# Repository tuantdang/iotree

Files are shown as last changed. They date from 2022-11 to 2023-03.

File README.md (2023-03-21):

## IoTree: A Battery-free Wearable System with Biocompatible Sensors for Continuous Tree Health Monitoring

[Project Page](https://github.com/tuantdang/iotree) | [Paper](https://dl.acm.org/doi/pdf/10.1145/3495243.3567652) | [Video](https://www.youtube.com/watch?v=8DUfOcuPwIk&ab_channel=TuanDang)

## Author Information
- [Tuan Dang,  University of Texas at Arlington](https://www.tuandang.info/)
- [Trung Tran,  Sungkyunkwan University](https://scholar.google.com/citations?user=2bYMOpEAAAAJ&hl=en)
- [Khang Nguyen,  University of Texas at Arlington](https://mkhangg.com/)
- [Tien Pham,  University of Texas at Arlington](https://sakewebsite.z19.web.core.windows.net/)
- [Nhat Pham, University of Oxford](https://www.nhatpham.info/)
- [Tam Vu, University of Colorado Boulder](http://mnslab.org/tamvu/)
- [Phuc Nguyen,  University of Texas at Arlington](http://wsslab.org/vpnguyen/)

 <p align="center">
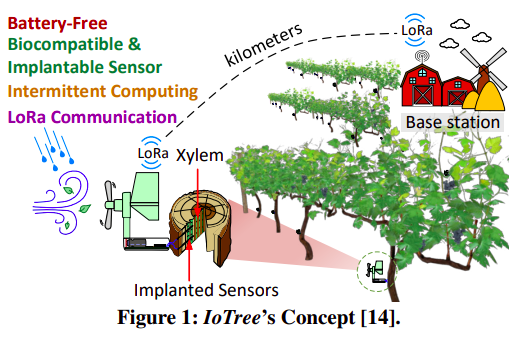
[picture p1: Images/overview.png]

</p>

## Abstract
In this paper, we present a low-maintenance, wind-powered, batteryfree, biocompatible, tree wearable, and intelligent sensing system,
namely IoTree, to monitor water and nutrient levels inside a living tree. IoTree system includes tiny-size, biocompatible, and implantable sensors that continuously measure the impedance variations inside the living tree’s xylem, where water and nutrients are
transported from the root to the upper parts. The collected data are
then compressed and transmitted to a base station located at up to 1.8
kilometers (approximately 1.1 miles) away. The entire IoTree system
is powered by wind energy and controlled by an adaptive computing
technique called block-based intermittent computing, ensuring the
forward progress and data consistency under intermittent power and
allowing the firmware to execute with the most optimal memory and
energy usage. We prototype IoTree that opportunistically performs
sensing, data compression, and long-range communication tasks
without batteries. During in-lab experiments, IoTree also obtains the
accuracy of 91.08% and 90.51% in measuring 10 levels of nutrients,
𝑁𝐻3 and 𝐾2𝑂, respectively. While tested with Burkwood Viburnum
and White Bird trees in the indoor environment, IoTree data strongly
correlated with multiple watering and fertilizing events. We also
deployed IoTree on a grapevine farm for 30 days, and the system is
able to provide sufficient measurements every day
 
 ## System Architecture
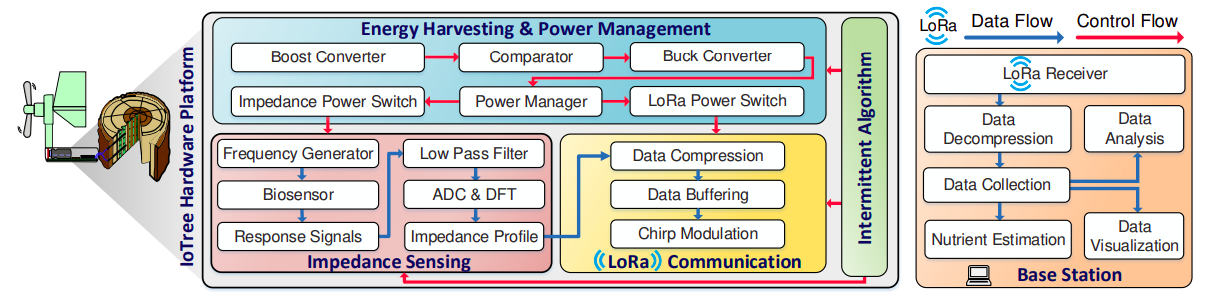
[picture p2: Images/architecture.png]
 
 
 ## Prototype
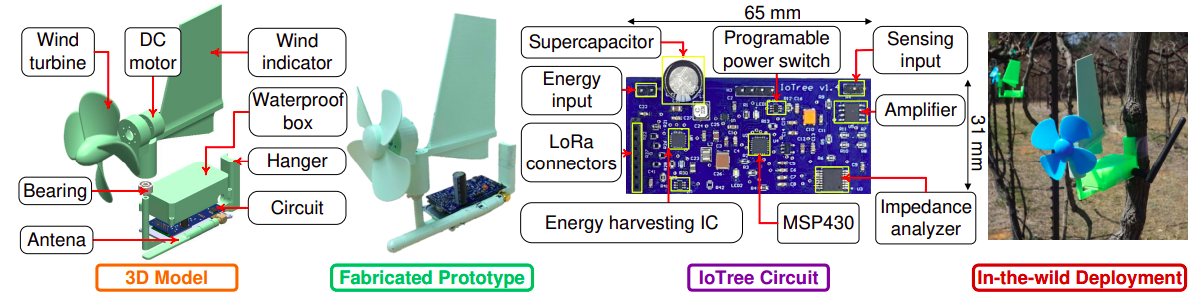
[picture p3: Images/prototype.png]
 
 
 ## Results
<p align="center">
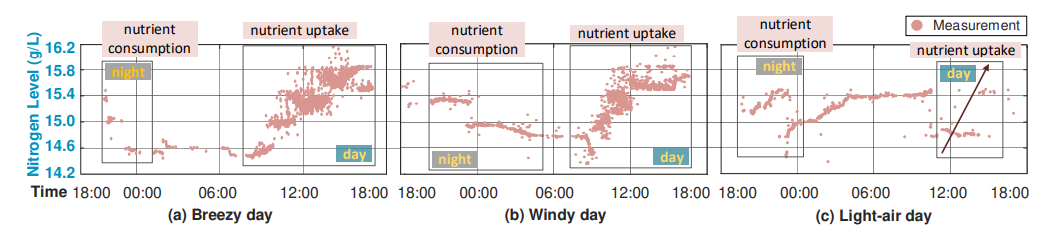
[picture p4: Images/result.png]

</p>

## Requirement
- Code Composer Studio 10.0
- MatLab
- Python 3.7 or above

## Acknowledgments

## Citing
```
@inproceedings{dang2022iotree,
  title={ioTree: a battery-free wearable system with biocompatible sensors for continuous tree health monitoring},
  author={Dang, Tuan and Tran, Trung and Nguyen, Khang and Pham, Tien and Pham, Nhat and Vu, Tam and Nguyen, Phuc},
  booktitle={Proceedings of the 28th Annual International Conference on Mobile Computing And Networking},
  pages={352--366},
  year={2022}
}
```

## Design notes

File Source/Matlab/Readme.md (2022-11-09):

 # GUI tool to collect data with indoor experiments
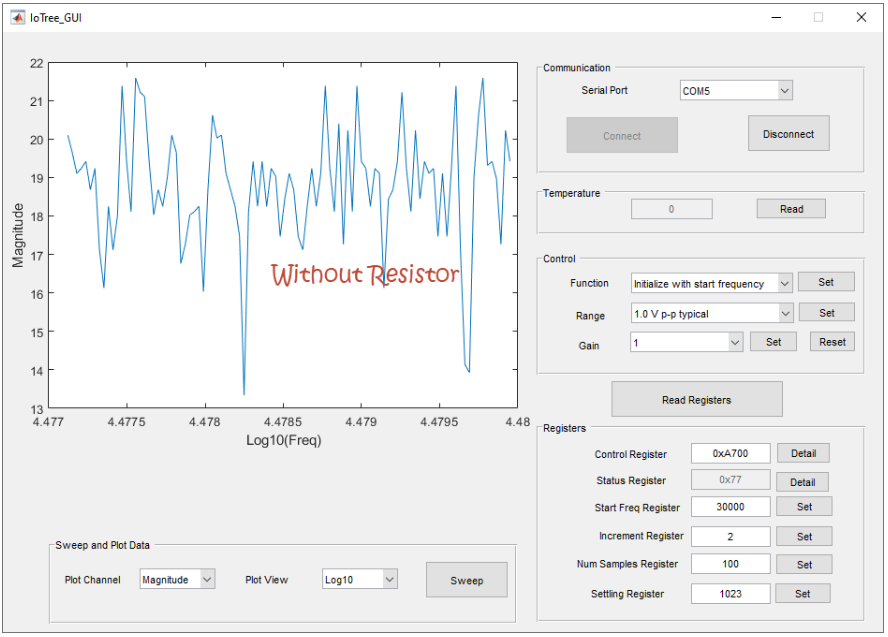
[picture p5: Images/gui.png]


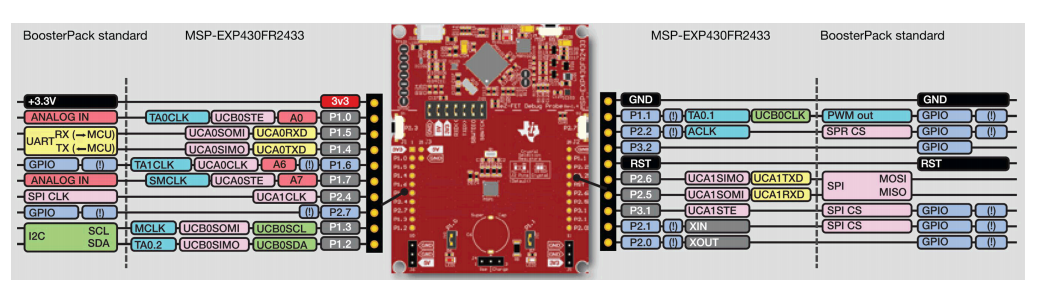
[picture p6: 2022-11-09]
Source/IoTree_MSP430FR2433_TestWisp/header-pinout.png

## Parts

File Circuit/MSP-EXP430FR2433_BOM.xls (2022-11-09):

Item # | Designator | Quantity | Manufacturer | PartNumber | Description | Supplier Part Number 1 | Note | REACH Compliant | RoHS Compliant
1 | !PCB | 1 | CM |  | MSP-EXP430FR2433 PCB
2 | !USB | 1 | Assman WSW | AK67421-0.3 | Cable, USB-A to micro USB-B, 0.3 m |  |  | Y | Y
3 | C1, C112 | 2 | MuRata | GRM155R71H102KA01D | CAP, CERM, 1000 pF, 50 V, +/- 10%, X7R, 0402 | 490-1303-1-ND |  | Y | Y
4 | C2, C3 | 2 | MuRata | GRM1555C1E120JA01D | CAP, CERM, 12 pF, 25 V, +/- 5%, C0G/NP0, 0402 | 81-GRM1555C1E120JA1D |  | Y | Y
5 | C4 | 1 | MuRata | GRM155R61H104ME14D | CAP, CERM, 0.1 µF, 50 V, +/- 20%, X5R, 0402 | GRM155R61H104ME14D-ND |  | Y | Y
6 | C5 | 1 | MuRata | GRM188R60J106ME84 | CAP, CERM, 10 µF, 6.3 V, +/- 20%, X5R, 0603 | 490-7316-1-ND |  | Y | Y
7 | C101 | 1 | MuRata | GRM155R61C474KE01 | CAP, CERM, 0.47 µF, 16 V, +/- 10%, X5R, 0402 |  |  | Y | Y
8 | C102, C107 | 2 | MuRata | GRM188R61C224KA88D | CAP, CERM, 0.22 µF, 16 V, +/- 10%, X5R, 0603 | GRM188R61C224KA88D-ND |  | Y | Y
9 | C103, C105, C113, C114, C118, C120, C121, C124, C125 | 9 | MuRata | GRM155R61A104KA01D | CAP, CERM, 0.1 µF, 10 V, +/- 10%, X5R, 0402 | 490-1318-1-ND |  | Y | Y
10 | C104 | 1 | Vishay-Sprague | 293D106X0010A2TE3 | CAP, TA, 10 µF, 10 V, +/- 20%, 3.4 ohm, SMD | 718-1118-1-ND |  | Y | Y
11 | C106, C109 | 2 | Vishay-Sprague | 293D475X9010A2TE3 | CAP, TA, 4.7 µF, 10 V, +/- 10%, 5 ohm, SMD | 718-1146-1-ND |  | Y | Y
12 | C108 | 1 | MuRata | GRM185R61A105KE36D | CAP, CERM, 1 µF, 10 V, +/- 10%, X5R, 0603 | 490-3893-1-ND |  | Y | Y
13 | C110, C111 | 2 | MuRata | GRM1555C1H100JA01D | CAP, CERM, 10 pF, 50 V, +/- 5%, C0G/NP0, 0402 | 81-GRM1555C1H100JA1D |  | Y | Y
14 | C115, C116, C122, C123 | 4 | MuRata | GRM1555C1H330JA01D | CAP, CERM, 33 pF, 50 V, +/- 5%, C0G/NP0, 0402 | 81-GRM1555C1H330JA1D |  | Y | Y
15 | C117, C119 | 2 | MuRata | GRM188R61C475KAAJ | CAP, CERM, 4.7 µF, 16 V, +/- 10%, X5R, 0603 | 490-10481-1-ND | Use Exact Part | Y | Y
16 | C126 | 1 | MuRata | GRM155R61A224KE19D | CAP, CERM, 0.22 µF, 10 V, +/- 10%, X5R, 0402 | 490-3910-1-ND |  | Y | Y
17 | D101, D102 | 2 | NXP Semiconductor | BAS40-05W,115 | Diode, Schottky, 40 V, 0.12 A, AEC-Q101, SOT-323 | 568-7982-1-ND | Use Exact Part | Y | Y
18 | IC101 | 1 | Texas Instruments | TLV70033DSET | Single Output LDO, 200 mA, Fixed 3.3 V Output, 2 to 5.5 V Input, with Low IQ, 6-pin WSON (DSE), -40 to 125 degC, Green (RoHS & no Sb/Br) | 296-25215-2-ND | TI Provided | Y | Y
19 | IC102 | 1 | Texas Instruments | TPD4E004DRYR | ESD-Protection Array for High-Speed Data Interfaces, 4 Channels, -40 to +85 degC, 6-pin SON (DRY), Green (RoHS & no Sb/Br) | 296-23618-2-ND | TI Provided | Y | Y
20 | IC103 | 1 | Texas Instruments | TS5A21366RSER | 0.75-Ohm DUAL SPST ANALOG SWITCH WITH 1.8-V COMPATIBLE INPUT LOGIC, RSE0008A (UQFN-8) |  | TI Provided | Y | Y
21 | J1, J2 | 2 | Samtec | SSQ-110-03-F-S | Receptacle, 2.54mm, 10x1, Gold, TH | 2283783 | Booster Pack 20 pin J1, Booster Pack 20 pin J2 | Y | Y
22 | J3 | 1 | Samtec | SSQ-102-03-F-S | Receptacle, 2.54mm, 2x1, Gold, TH | 2283777 | Booster Pack 20 pin J3 | Y | Y
23 | J4, J5, J6 | 3 | Sullins Connector Solutions | PEC03SAAN | Header, 100mil, 3x1, Tin, TH | S1012E-03-ND |  | Y | Y
24 | J10, J11 | 2 | Samtec | TSW-102-07-G-S | Header, 100mil, 2x1, Gold, TH | SAM1029-02-ND |  | Y | Y
25 | J101 | 1 | Sullins Connector Solutions | PEC07DAAN | Header, 100mil, 7x2, Tin, TH | S2012E-07-ND |  | Y | Y
26 | J102 | 1 | Molex | 1051640001 | Receptacle, USB 2.0, Micro B, 5 Position, R/A, SMT | WM11263CT-ND | Use Exact Part | Y | Y
27 | L101 | 1 | Taiyo Yuden | CBC2518T2R2M | Inductor, Wirewound, Ceramic, 2.2 µH, 0.89 A, 0.13 ohm, SMD | 587-1618-1-ND | Use Exact Part | Y | Y
28 | L102, L103 | 2 | Wurth Elektronik | 742792622 | Ferrite Bead, 180 ohm @ 100 MHz, 0.5 A, 0603 | 732-1580-1-ND |  | Y | Y
29 | LED1, LED101 | 2 | Lite-On | LTST-C190CKT | LED, Red, SMD | 160-1181-1-ND |  | Y | Y
30 | LED2, LED102 | 2 | Lite-On | LTST-C190GKT | LED, Green, SMD | 160-1183-1-ND |  | Y | Y
31 | MSP1 | 1 | Texas Instruments | MSP430FR2433IRGER | MSP430FR2433 16 MHz Ultra-Low-Power Microcontroller with 16 KB FRAM, 4 KB RAM, 19 IO, 4 Timers, RGE0024H (VQFN-24) |  | TI Provided | Y | Y
32 | MSP101 | 1 | Texas Instruments | MSP430F5528IRGCT | 25 MHz Mixed Signal Microcontroller with 128 KB Flash, 8192 B SRAM and 47 GPIOs, -40 to 85 degC, 64-pin QFN (RGC), Green (RoHS & no Sb/Br) |  | TI Provided | Y | Y
33 | MSP102 | 1 | Texas Instruments | MSP430G2452IRSA16R | 16 MHz Mixed Signal Microcontroller with 8 KB Flash, 256 B SRAM and 16 GPIOs, 16-pin QFN (RSA), Green (RoHS & no Sb/Br) |  | TI Provided | Y | Y
34 | Q1 | 1 | Epson | X1A0001410014 | Crystal, 32.768 KHz, 12.5 pF, SMD |  | Use Exact Part, TI Provided | Y | Y
35 | Q101 | 1 | MuRata | CSTCR4M00G15L99-R0 | Resonator, 4MHz, 39pF SMD | 490-7861-1-ND | Use Exact Part | Y | Y
36 | R1 | 1 | Yageo America | RC0402FR-0747KL | RES, 47.0 k, 1%, 0.0625 W, 0402 | 311-47.0KLRCT-ND |  | Y | Y
37 | R4, R5 | 2 | Vishay-Dale | CRCW06030000Z0EA | RES, 0, 5%, 0.1 W, 0603 | 541-0.0GCT-ND |  | Y | Y
38 | R6 | 1 | Yageo America | RC0402FR-07470RL | RES, 470, 1%, 0.063 W, 0402 | 311-470LRCT-ND |  | Y | Y
39 | R7 | 1 | Vishay-Dale | CRCW0402392RFKED | RES, 392, 1%, 0.063 W, 0402 | 541-392LCT-ND |  | Y | Y
40 | R8 | 1 | Vishay-Dale | CRCW120622R0JNEA | RES, 22, 5%, 0.25 W, 1206 | 541-22ECT-ND |  | Y | Y
41 | R101, R120 | 2 | Vishay-Dale | CRCW0402470RJNED | RES, 470, 5%, 0.063 W, 0402 | 541-470JCT-ND |  | Y | Y
42 | R102 | 1 | Vishay-Dale | CRCW0402390RJNED | RES, 390, 5%, 0.063 W, 0402 | 541-390JCT-ND |  | Y | Y
43 | R103, R104 | 2 | Vishay-Dale | CRCW040227R0JNED | RES, 27, 5%, 0.063 W, 0402 | 541-27JCT-ND |  | Y | Y
44 | R105 | 1 | Vishay-Dale | CRCW04021K40FKED | RES, 1.40 k, 1%, 0.063 W, 0402 | 541-1.40KLCT-ND |  | Y | Y
45 | R106 | 1 | Vishay-Dale | CRCW04021M00JNED | RES, 1.0 M, 5%, 0.063 W, 0402 | 541-1.0MJCT-ND |  | Y | Y
46 | R107, R108 | 2 | TE Connectivity | CRG0402F4K7 | RES, 4.70 k, 1%, 0.063 W, 0402 | A121542CT-ND |  | Y | Y
47 | R109 | 1 | Vishay-Dale | CRCW040247K0JNED | RES, 47 k, 5%, 0.063 W, 0402 | 541-47KJCT-ND |  | Y | Y
48 | R112, R113, R114, R115, R121, R122 | 6 | Vishay-Dale | CRCW0402221KFKED | RES, 221 k, 1%, 0.063 W, 0402 | 541-221KLCT-ND |  | Y | Y
49 | R116, R117 | 2 | Vishay-Dale | CRCW04024K70JNED | RES, 4.7 k, 5%, 0.063 W, 0402 | 541-4.7KJCT-ND |  | Y | Y
50 | R118 | 1 | Yageo America | RC0402FR-07820RL | RES, 820, 1%, 0.063 W, 0402 | 311-820LRCT-ND |  | Y | Y
51 | R119 | 1 | Vishay-Dale | CRCW04020000Z0ED | RES, 0, 5%, 0.063 W, 0402 | 541-0.0JCT-ND |  | Y | Y
52 | R123 | 1 | Vishay-Dale | CRCW040233K0JNED | RES, 33 k, 5%, 0.063 W, 0402 | 541-33KJCT-ND |  | Y | Y
53 | R124 | 1 | Vishay-Dale | CRCW0402240KFKED | RES, 240 k, 1%, 0.063 W, 0402 | 541-240KLCT-ND |  | Y | Y
54 | R125 | 1 | Vishay-Dale | CRCW0402150KFKED | RES, 150 k, 1%, 0.063 W, 0402 | 541-150KLCT-ND |  | Y | Y
55 | R126 | 1 | Vishay-Dale | CRCW04022K20FKED | RES, 2.20 k, 1%, 0.063 W, 0402 | 541-2.20KLCT-ND |  | Y | Y
56 | R127 | 1 | Panasonic | ERJ-2RKF3301X | RES, 3.30 k, 1%, 0.1 W, AEC-Q200 Grade 0, 0402 | P3.30KLCT-ND |  | Y | Y
57 | R128 | 1 | Vishay-Dale | CRCW04026K81FKED | RES, 6.81 k, 1%, 0.063 W, 0402 | 541-6.81KLCT-ND |  | Y | Y
58 | R129, R130 | 2 | Vishay-Dale | CRCW040210R0FKED | RES, 10.0, 1%, 0.063 W, 0402 | 541-10.0LCT-ND |  | Y | Y
59 | S1, S2, S3 | 3 | Diptronics | 1188E-1K2-V-TR | Switch, SPST, 0.05 A, 12 VDC, SMD |  |  | Y | Y
60 | SH-J10, SH-J11, SH-J101-1, SH-J101-2, SH-J101-3, SH-J101-4, SH-J101-5, SH-J101-6, SH-J101-7 | 9 | Samtec | SNT-100-BK-G | Shunt, 100mil, Gold plated, Black | SNT-100-BK-G-ND | J10: 1-2, J11: 1-2, J101: 1-2, J101: 3-4, J101: 5-6, J101: 7-8, J101: 9-10, J101: 11-12, J101: 13-14 | Y | Y
61 | T101 | 1 | Diodes Inc. | DMG1013UW-7 | MOSFET, P-CH, -20 V, -0.82 A, SOT-323 | DMG1013UW-7DICT-ND | Use Exact Part | Y | Y
62 | T102 | 1 | NXP Semiconductor | BC850CW,115 | Transistor, NPN, 45 V, 0.1 A, SOT-323 | 568-6076-1-ND | Use Exact Part | Y | Y
63 | C6 | 0 | Panasonic | EEC-S0HD224H | CAP, Electric Double Layer, 220000 µF, 5.5 V, +80/-20%, TH | P10788-ND | DNP
64 | C127 | 0 | MuRata | GRM1555C1H101JA01D | CAP, CERM, 100 pF, 50 V, +/- 5%, C0G/NP0, 0402 | 81-GRM1555C1H101JA1D | DNP
65 | R2, R3 | 0 | Vishay-Dale | CRCW06030000Z0EA | RES, 0, 5%, 0.1 W, 0603 | 541-0.0GCT-ND | DNP
66 | SH-J4 | 0 | Samtec | SNT-100-BK-G | Shunt, 100mil, Gold plated, Black | SNT-100-BK-G-ND | DNP, J4: 2
67 | TP101, TP102, TP103, TP104, TP105, TP106, TP107, TP108, TP109 | 0 | Keystone | 5001 | Test Point, Miniature, Black, TH | 36-5001-ND | DNP

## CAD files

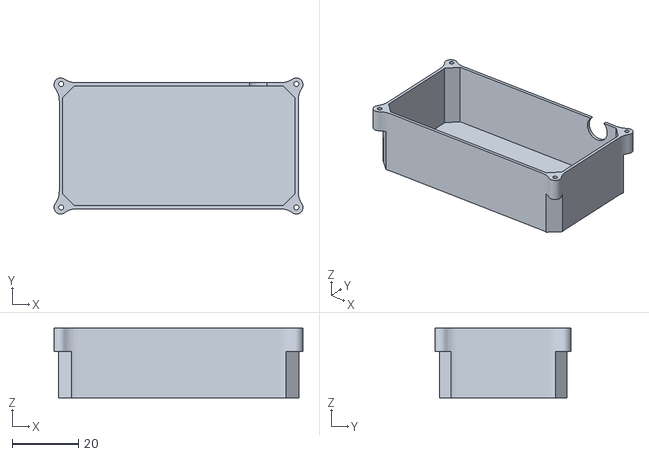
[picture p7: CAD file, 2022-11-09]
3D_Models/upper_box.STL
75.0 x 41.0 x 21.0

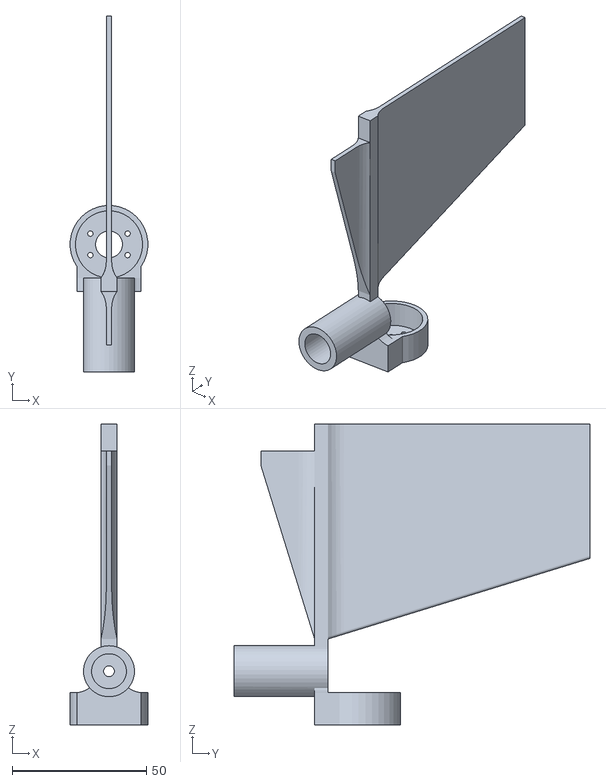
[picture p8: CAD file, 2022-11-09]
3D_Models/motor_mount_nav.STL
28.9 x 132.5 x 112.0

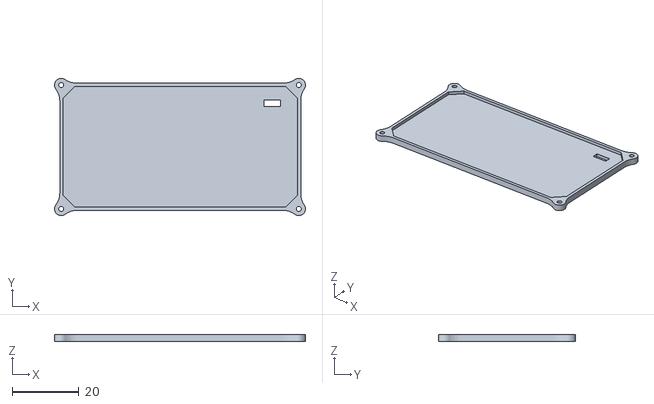
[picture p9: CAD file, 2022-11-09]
3D_Models/base.STL
75.0 x 41.0 x 2.00

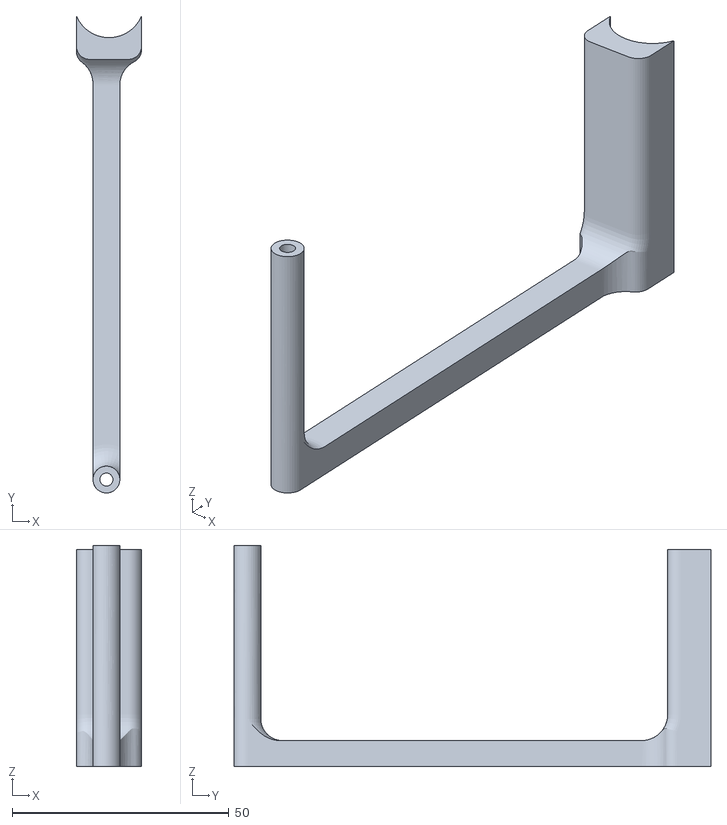
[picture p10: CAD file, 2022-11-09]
3D_Models/WindHarvester.STL
15.0 x 110.0 x 51.0

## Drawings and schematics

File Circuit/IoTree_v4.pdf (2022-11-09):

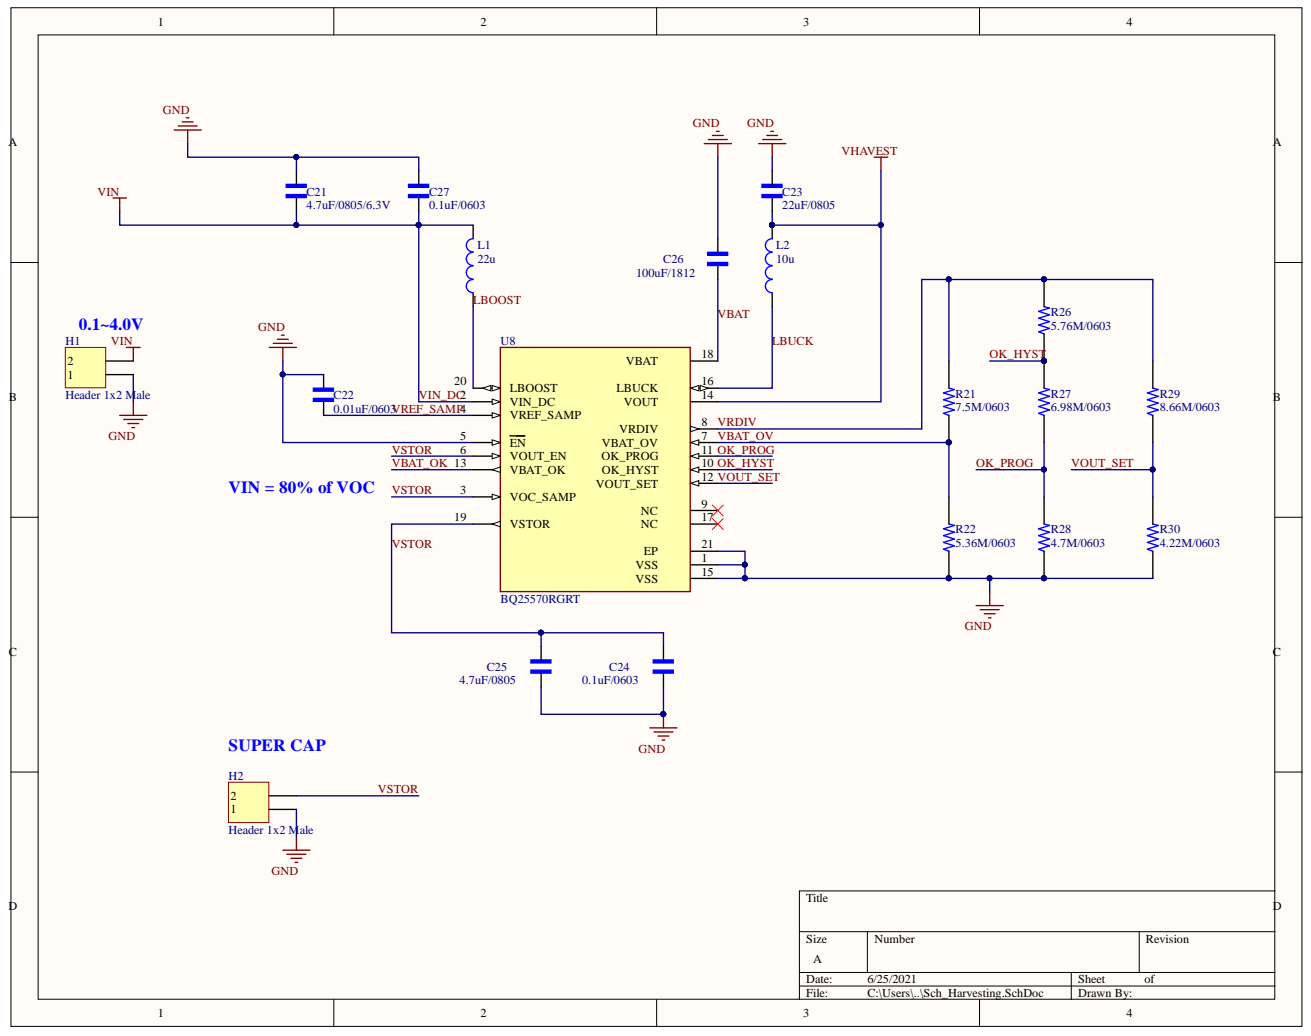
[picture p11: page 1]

VIN = 80% of VOC VSTOR

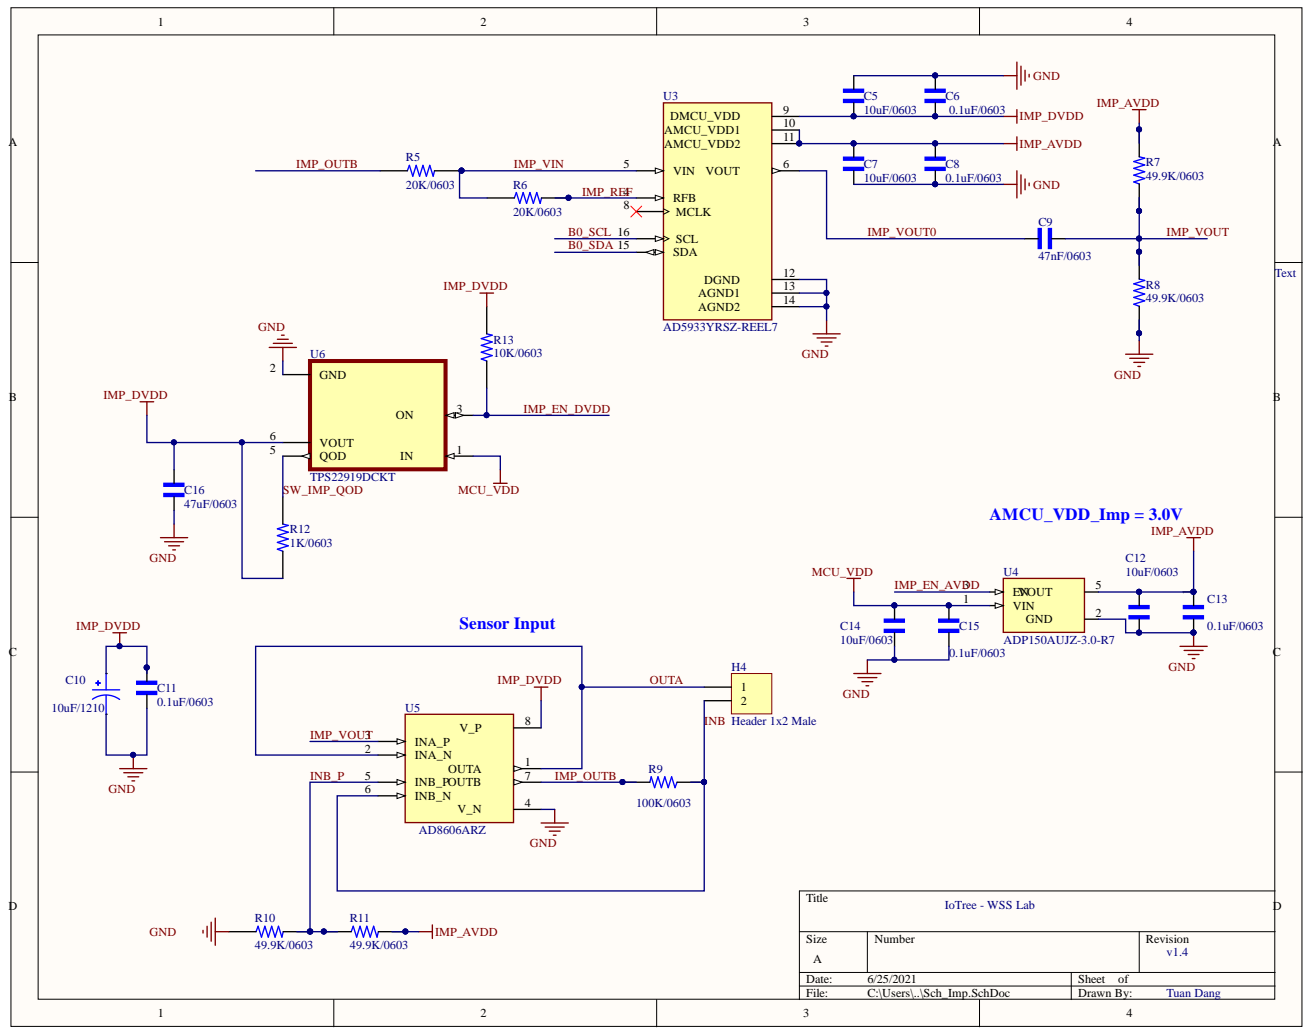
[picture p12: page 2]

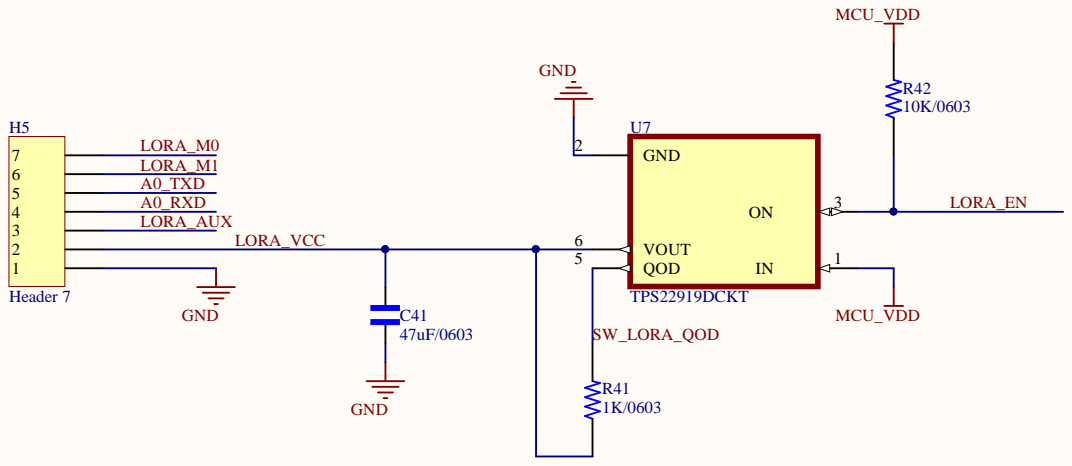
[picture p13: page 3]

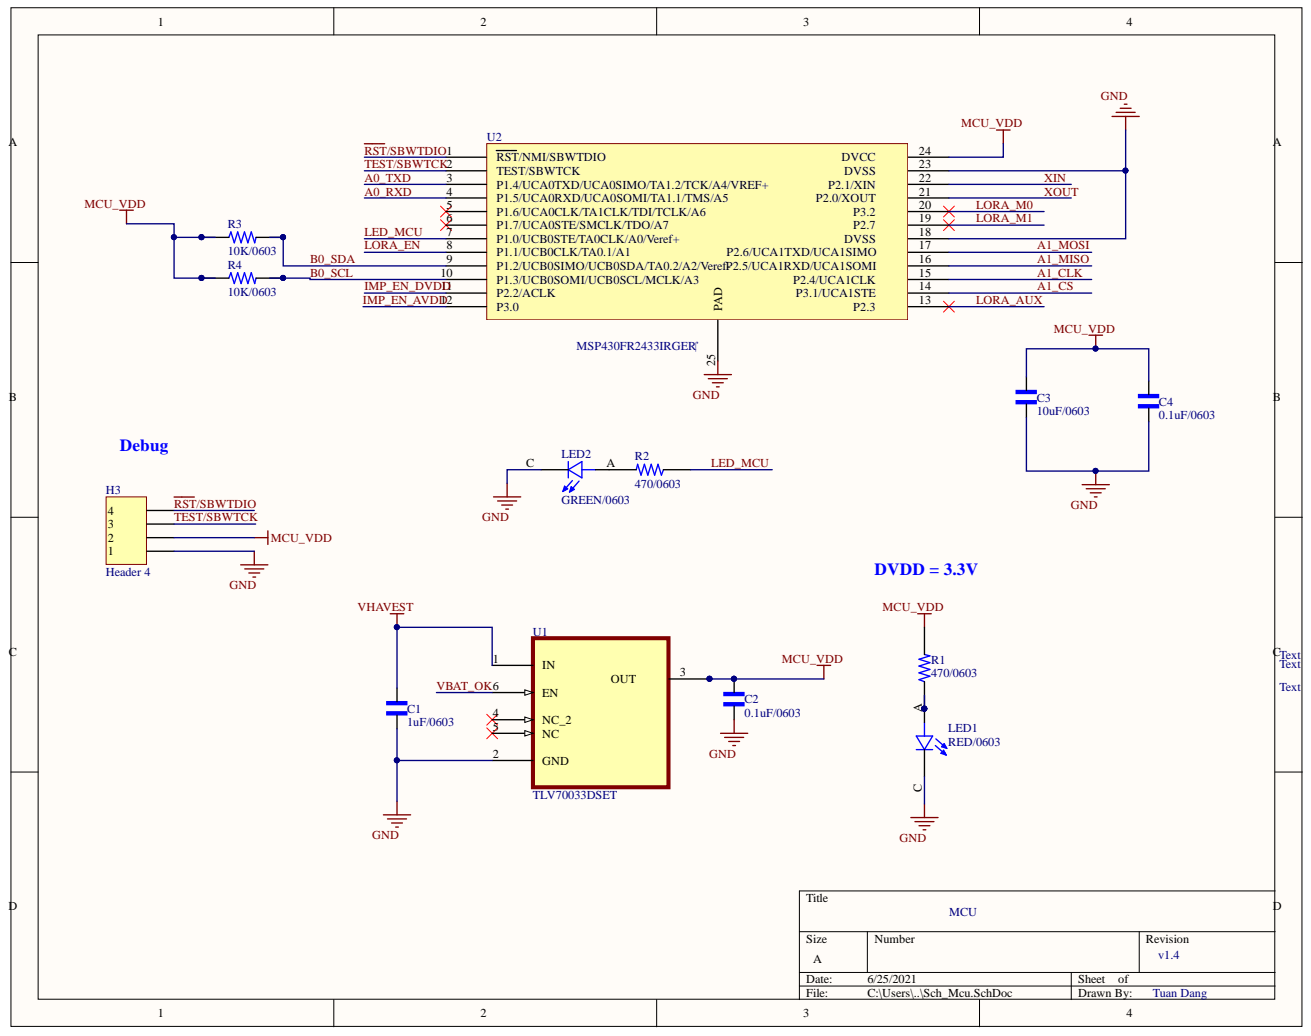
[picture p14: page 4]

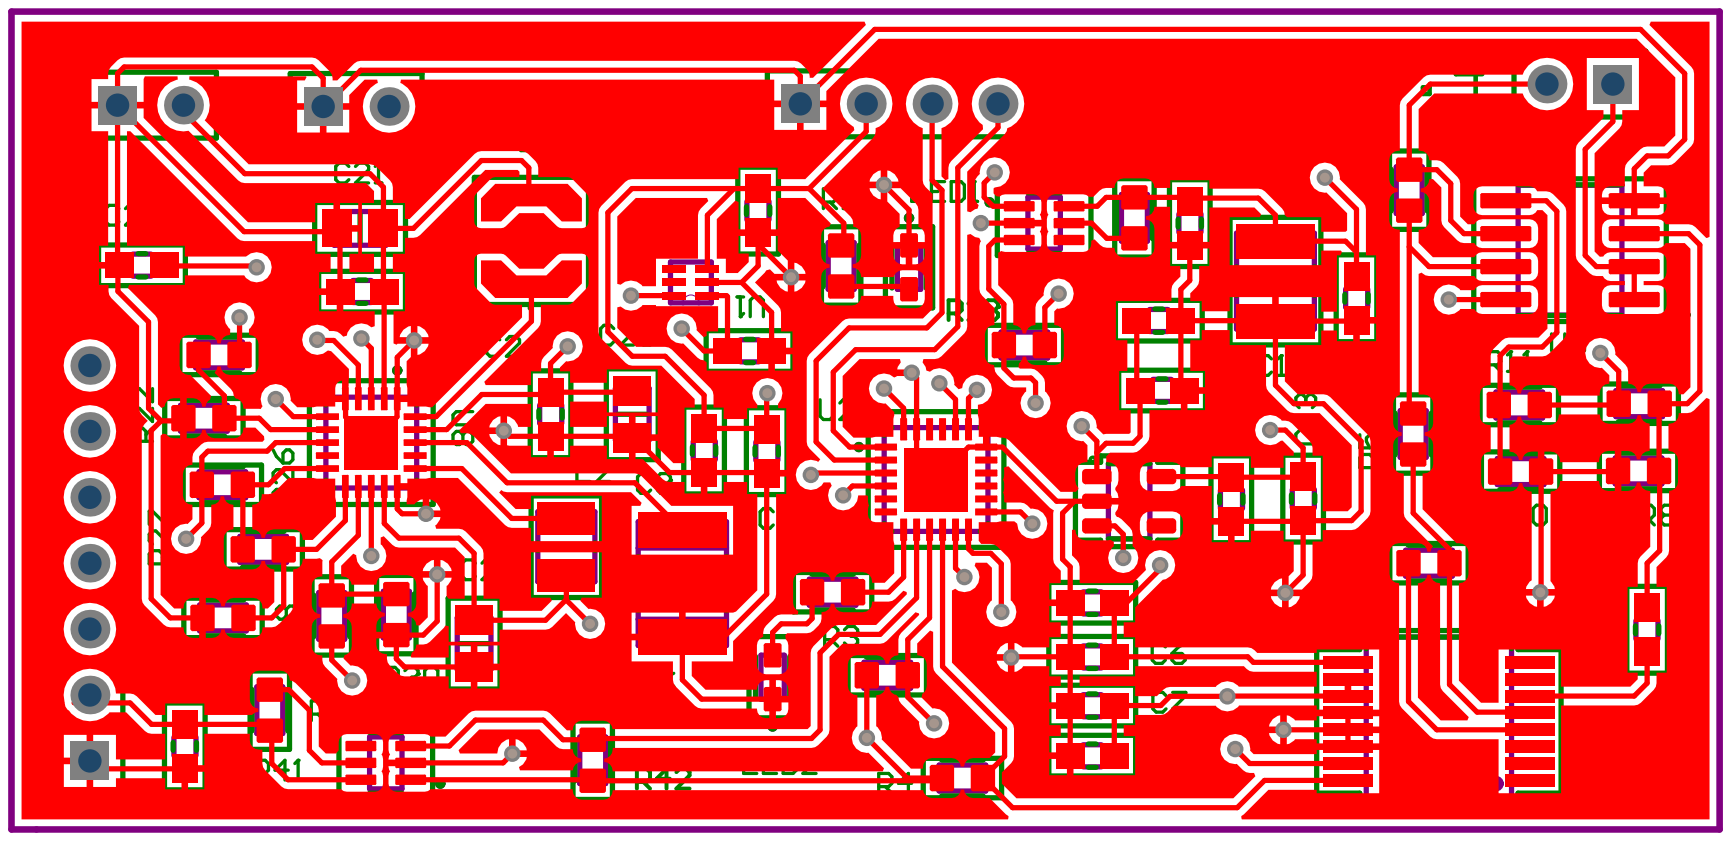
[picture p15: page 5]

# Board S

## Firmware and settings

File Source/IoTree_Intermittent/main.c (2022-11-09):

#include <msp430.h>
#include <stdint.h>
#include <stdbool.h>
#include "AD5933.h"
#include "serial.h"
#include <string.h>

#include "lib.h"
#include "task.h"

/* By turn of this option we can test the correctness of intermittent computing block-based approach
 * Three tasks and each task has a number of blocks */
//#define TEST_INTERMITTENT

/* User code forward declaration*/
/* A task will be divided into multiple block from block id = 0 to block id = N*/
/* User can handle  operation within specific block with block id*/
/* Input data & output data belongs to block id*/
/* Run-time library will protect output data in case of power failure*/
void sense_block_handler(uint8_t* bid,  uint8_t* bnum, uint8_t* ibuf, uint8_t* obuf);
void compress_block_handler(uint8_t* bid,  uint8_t* bnum, uint8_t* ibuf, uint8_t* obuf);
void transmit_block_handler(uint8_t* bid,  uint8_t* bnum, uint8_t* ibuf, uint8_t* obuf);

void main(void)
{
    init_system();
    /* These lines of code only run for the first time */
    if (IS_FIRST_RUN())
    {
        reset_fram();
        init_tasks();
        set_user_func(TASK_SENSE, sense_block_handler);
        set_user_func(TASK_COMPRESS, compress_block_handler);
        set_user_func(TASK_TRANSMIT, transmit_block_handler);

        //Block number is set based on previous energy consumption
        //and can be changed inside user code for each task
#if defined(USE_MUL_SENSE_BLOCK)
        set_block_number(TASK_SENSE, 2); //2 for low-high ranges sweeping frequencies
#else
        set_block_number(TASK_SENSE, 1); //2 for low-high ranges sweeping frequencies
#endif
        set_block_number(TASK_COMPRESS, 1);
        set_block_number(TASK_TRANSMIT, 1);
        MARK_FIRST_RUN();
    }
    start(); //Start System
}

/* User code start here */
/* Sensing task
 *Parameter bid: block id
 *Parameter buf: volatile memory which is eventual written in run-time library
 *Therefore, data consistency is protected by run-time library, user only working volatile memory provided by the interface (bid, buf)
*/
unsigned long test = 0;
uint8_t flag_init_sense = OFF;
uint8_t numSamples = 0, counter = 0, status = 0;
int16_t realData = 0, imgData = 0;
void sense_block_handler(uint8_t* ptr_bid, uint8_t* ptr__bnum, uint8_t* ibuf,  uint8_t* obuf){
#define FREQ_NUM 16

    /*Handle as entire a task*/
#if defined(TEST_INTERMITTENT)
   led_power(ON);
   __delay_cycles(TIME_100MS);
   led_power(OFF);
   __delay_cycles(TIME_100MS);
   int i = 0;
   for(i = 0; i < bnum; i++){
       obuf[i] = i;
   }

   /*Handle specific block by block id*/
   switch (bid){
   case 0:
       //User code here
       //blokc1();
       break;
   case 1:
       //User code here
       //blokc2();
       break;

   case 2:
       //User code here
       break;
   default: break;
   }

#else
   /* Static volatile variable holding state of user code to avoid duplicated initialization */

      //static unsigned long freq[FREQ_NUM] = {10000, 11000, 12000, 13000, 14000, 15000, 16000, 17000, 18000, 19000,  100000, 200000, 300000, 400000, 500000, 600000};




       //__delay_cycles(TIME_10MS);

       if (flag_init_sense == OFF){
           flag_init_sense = ON;
           //power(POWER_SENSING, ON);
           //power(POWER_COMM, OFF);
           AD5933_Init(); //I2C
           __enable_interrupt();
       }

       power(POWER_SENSING, ON);
       __delay_cycles(TIME_20MS);
       //led_power(ON);

#if defined(USE_MUL_SENSE_BLOCK)
       if (*ptr_bid == 0)
#endif
       {
          uint8_t RegCtlH = 0;
          RegCtlH = AD5933_GetRegisterValue(AD5933_CONTROL_REG_HB, 1);
          AD5933_SetRegisterValue(AD5933_NR_SETTLE_REG_HB, 0, 1);
          AD5933_SetRegisterValue(AD5933_NR_SETTLE_REG_LB, 10, 1);
          RegCtlH = RegCtlH & 0xFE; //Clear D8s
          RegCtlH = RegCtlH | 1; //D8 = 1: Gain = 1; If D8=0: Gain = 5;
          AD5933_SetRegisterValue(AD5933_CONTROL_REG_HB, RegCtlH, 1);
          __delay_cycles(TIME_10MS);

           numSamples = 10;
           counter = 0;
           //AD5933_SetRegisterValue(AD5933_START_FREQ_REG_HB, VAL2REG_FREQ(freq[*ptr_bid]), 3);
           AD5933_SetRegisterValue(AD5933_START_FREQ_REG_HB, VAL2REG_FREQ(10000), 3);
           AD5933_SetRegisterValue(AD5933_FREQ_INCR_REG_HB, VAL2REG_FREQ(1000), 3);
           AD5933_SetRegisterValue(AD5933_NR_INCR_REG_HB, numSamples, 2);
           AD5933_StartSweep();
           while (1)
           {
              //While for real/image conversion
              while ((status & AD5933_STATUS_DATA_VALID) == 0)
              {
                  status = AD5933_GetRegisterValue(AD5933_STATUS_REG, 1);
              }
              realData = AD5933_GetRegisterValue(AD5933_REAL_REG_HB, 2);
              imgData = AD5933_GetRegisterValue(AD5933_IMG_REG_HB, 2);

              //memcpy(obuf + (*ptr_bid)*4, &realData, 2);
              //memcpy(obuf + (*ptr_bid)*4 + 2, &imgData, 2);
              memcpy(obuf + counter*4, &realData, 2);
              memcpy(obuf + counter*4 + 2, &imgData, 2);

              status = AD5933_GetRegisterValue(AD5933_STATUS_REG, 1);
              if ((status & AD5933_STATUS_SWEEP_DONE) != 0) break;
              else
              {
                  AD5933_SetRegisterValue( AD5933_CONTROL_REG_HB, AD5933_CONTROL_FUNCTION(AD5933_INCR_FREQ), 1);
              }
              counter++;
              if (counter >= numSamples) break;
           }
       }
#if defined(USE_MUL_SENSE_BLOCK)
       else
#endif
       {
           numSamples = 6;
            counter = 0;
            //AD5933_SetRegisterValue(AD5933_START_FREQ_REG_HB, VAL2REG_FREQ(freq[*ptr_bid]), 3);
            AD5933_SetRegisterValue(AD5933_START_FREQ_REG_HB, VAL2REG_FREQ(100000), 3);
            AD5933_SetRegisterValue(AD5933_FREQ_INCR_REG_HB, VAL2REG_FREQ(100000), 3);
            AD5933_SetRegisterValue(AD5933_NR_INCR_REG_HB, numSamples, 2);
            AD5933_StartSweep();
            while (1)
            {
                 //While for real/image conversion
                 while ((status & AD5933_STATUS_DATA_VALID) == 0)
                 {
                     status = AD5933_GetRegisterValue(AD5933_STATUS_REG, 1);
                 }
                 realData = AD5933_GetRegisterValue(AD5933_REAL_REG_HB, 2);
                 imgData = AD5933_GetRegisterValue(AD5933_IMG_REG_HB, 2);

                 //memcpy(obuf + (*ptr_bid)*4, &realData, 2);
                 //memcpy(obuf + (*ptr_bid)*4 + 2, &imgData, 2);
                 memcpy(obuf + 4*10 + counter*4, &realData, 2);
                 memcpy(obuf + 4*10 + counter*4 + 2, &imgData, 2);

                 status = AD5933_GetRegisterValue(AD5933_STATUS_REG, 1);
                 if ((status & AD5933_STATUS_SWEEP_DONE) != 0) break;
                 else
                 {
                     AD5933_SetRegisterValue( AD5933_CONTROL_REG_HB, AD5933_CONTROL_FUNCTION(AD5933_INCR_FREQ), 1);
                 }
                 counter++;
                 if (counter >= numSamples) break;
            }
       }
       AD5933_SetRegisterValue(AD5933_CONTROL_REG_HB, AD5933_CONTROL_FUNCTION(AD5933_POWER_DOWN), 1);
       power(POWER_SENSING, OFF);
       //led_power(OFF);
#endif
}


/* Compressing data task
 *Parameter bid: block id
 *Parameter buf: volatile memory which is eventual written in run-time library */
void compress_block_handler(uint8_t* ptr_bid, uint8_t* ptr__bnum,  uint8_t* ibuf,  uint8_t* obuf){
#if defined(TEST_INTERMITTENT)
    led_power(ON);
    __delay_cycles(TIME_1SEC);
    __delay_cycles(TIME_1SEC);
    //__delay_cycles(TIME_1SEC);
    //__delay_cycles(TIME_1SEC);
    //__delay_cycles(TIME_1SEC);
    led_power(OFF);
    int i = 0;
    for(i = 0; i < bnum; i++){
        obuf[i] = i*2;
    }
#else
    //Do Human code
    //uint8_t number = get_block_number(TASK_COMPRESS);
    //uint8_t size = SHARED_MEM_SIZE/number;
    //memcpy(obuf, ibuf, size);
    memcpy(obuf, ibuf, SHARED_MEM_SIZE);
#endif
}


#define SENSOR_ID   0x01

/* Transmitting data task
 *Parameter bid: block id
 *Parameter buf: volatile memory which is eventual written in run-time library */
uint8_t flag_init_transmit = OFF;
uint8_t header[3]= {0x0D, 0x0A, SENSOR_ID};
void transmit_block_handler(uint8_t* ptr_bid, uint8_t* ptr__bnum,  uint8_t* ibuf,  uint8_t* obuf){
#if defined(TEST_INTERMITTENT)
    led_power(ON);
   __delay_cycles(TIME_500MS);
   led_power(OFF);
   __delay_cycles(TIME_500MS);
   int i = 0;
     for(i = 0; i < bnum; i++){
         obuf[i] = i*3;
     }

#else
   /* Static volatile variable holding state of user code to avoid duplicated initialization */
   power(POWER_COMM, ON);
   __delay_cycles(TIME_10MS);

   if (flag_init_transmit == OFF){
       flag_init_transmit = ON;
      lora_config(LORA_MODE_NORMAL);
      Serial_init(UART_9600);
      __enable_interrupt();
      __delay_cycles(TIME_10MS);
   }

   //uint8_t number = get_block_number(TASK_TRANSMIT);
   //uint8_t size = SHARED_MEM_SIZE/number;
#define CHUNCK_SIZE 32      //=(64/4): Use hard code for better speed
   if (*ptr_bid == 0){
       Serial_write(header, 3);
       //Serial_write(ibuf, CHUNCK_SIZE);
       Serial_write(ibuf, 2 + 4*3);
       __delay_cycles(TIME_10MS);
   }
   else{
       //Serial_write(ibuf, CHUNCK_SIZE);
   }
   __delay_cycles(TIME_50MS);
   __delay_cycles(TIME_100MS);
   //__delay_cycles(TIME_100MS);
   //power(POWER_COMM, OFF);
#endif
}

/*
uint8_t is_first_run(){
    return (RESTORE((unsigned char*)RESET_FRAM_BIT_ADDR) == 0);
}

void mark_first_run(){
    extern task_t** current_task;
    extern task_t*  sensing_task;
    SYSCFG0 = FRWPPW | PFWP;
    CHECKPOINT(current_task, sensing_task);
    CHECKPOINT(((unsigned char*)RESET_FRAM_BIT_ADDR), 1);
    SYSCFG0 = FRWPPW | PFWP | DFWP;
}*/

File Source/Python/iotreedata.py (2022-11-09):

import serial
from datetime import datetime
s = serial.Serial(port='COM8', baudrate=9600, timeout=None)

logfileName = "test.csv"
fid = open(logfileName, "w")
count = 0
print("Start logging...");
#while count < N:    
line = 0
N = 64
while 1:
    try:        
        text = str(datetime.now())+ ","
        i = 0;
        while i < N:
            res = s.read(1);                           
            #print(i, " : ", res[0])
            text += " {:02X}".format(res[0])            
            i += 1
        fid = open(logfileName, "a")
        fid.write(text  + "\n")
        fid.close()
        line += 1        
        print(line, ": ", text)
        count = count + 1
    except Exception as ex:
        print(ex)        
        break    
s.close()
